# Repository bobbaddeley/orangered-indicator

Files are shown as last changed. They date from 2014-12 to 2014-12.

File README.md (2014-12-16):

orangered-indicator
===================

A tiny edge-lit display powered by a Spark Core that connects to reddit and checks for new messages. You could modify the code to check other web sites, and the edge lit display could be any icon you want. I specifically wanted to check Reddit, so I used the envelope icon.

See http://imgur.com/a/GfWCG for a full album of the completed project.

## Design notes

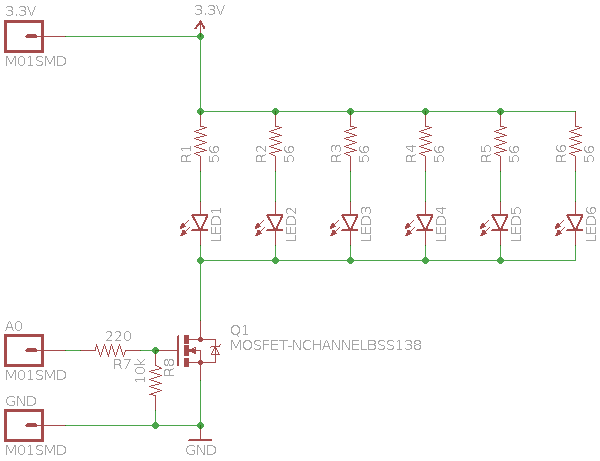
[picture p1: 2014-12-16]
schematic.png

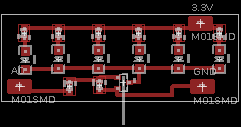
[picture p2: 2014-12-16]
board.png

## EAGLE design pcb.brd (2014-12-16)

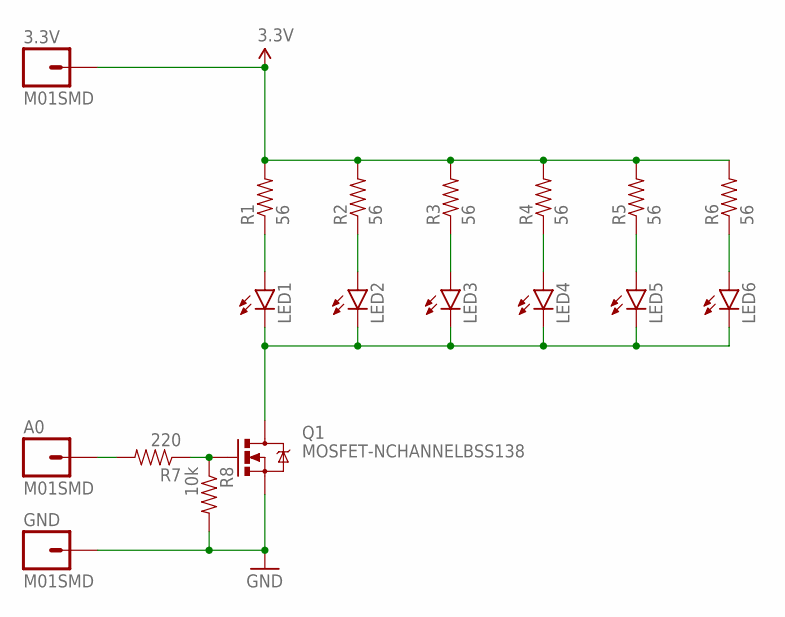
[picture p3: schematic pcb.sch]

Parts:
3.3V: M01SMD; LUXEON-PAD
A0: M01SMD; LUXEON-PAD
GND: M01SMD; LUXEON-PAD
LED1, LED2, LED3, LED4, LED5, LED6: LED1206; LED-1206
Q1: MOSFET-NCHANNELBSS138; SOT23-3
R1, R2, R3, R4, R5, R6: 56; 0603-RES
R7: 220; 0603-RES
R8: 10k; 0603-RES

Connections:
3.3V: 3.3V.P$1, R1.2, R2.2, R3.2, R4.2, R5.2, R6.2
GND: GND.P$1, Q1.2 (S), R8.2
unnamed: LED1.A, R1.1
unnamed: LED1.C, LED2.C, LED3.C, LED4.C, LED5.C, LED6.C, Q1.3 (D)
unnamed: A0.P$1, R7.2
unnamed: Q1.1 (G), R7.1, R8.1
unnamed: LED2.A, R2.1
unnamed: LED3.A, R3.1
unnamed: LED4.A, R4.1
unnamed: LED5.A, R5.1
unnamed: LED6.A, R6.1

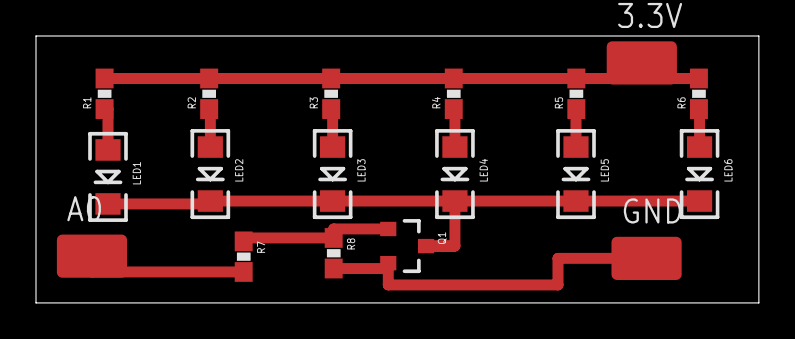
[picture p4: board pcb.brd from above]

Board: 2 copper layers, 40.2 x 14.8 mm, 18 parts (0 on the bottom side), 11 nets.

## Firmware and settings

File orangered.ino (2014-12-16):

//for the breathing of the LEDs, we do math.
#include "math.h"

//reddit username and password
char *username = "<YOURUSERNAME>";
char *password = "<YOURPASSWORD>";
//a custom user-agent because Reddit's API terms want one.
char *user_agent = "Spark Core IoT Orangered Indicator-1.0 by bobbaddeley";

//Debug mode dumps a bunch of stuff to the serial port
bool debug = false;

//how often do we check for updates
//currently every minute because we don't need to piss off Reddit
//and a minute is fine.
unsigned int frequency = 60;

TCPClient client;
unsigned int nextTime = 0;    // Next time to contact the server
//are we currently connected?
bool connected = false;
//the data that comes in from the server gets added to this string
String line = "";
//we have to send the cookie value with requests
String cookie = "";
//the output LED
int ledPin =A0; // Orange LEDs
int led2 = D7; //for debugging - built in LED
//location of the has_mail variable in the response json
int has_mail = 0;
bool mail_active = false;

void setup()
{
  //make the Spark status LED shut up.
  RGB.control(true); 
  RGB.color(0, 0, 0);
  //make the LED an output
  pinMode(ledPin, OUTPUT);
  pinMode(led2, OUTPUT);
  if (debug){
      // Make sure your Serial Terminal app is closed before powering your Core
      Serial.begin(38400);
      // Now open your Serial Terminal, and hit any key to continue!
      while(!Serial.available()) SPARK_WLAN_Loop();
      Serial.println("connecting...");
  }
  else {
    //for some reason, we can't immediately make a request, so we'll wait a bit for things to be ready
    delay(10000);
  }
  //connect to the server and log in.
  if (client.connect("reddit.com", 80))
  {
    connected = true;
    if (debug){Serial.println("connected");}
    client.print("POST /api/login?user=");
    client.print(username);
    client.print("&passwd=");
    client.print(password);
    client.println("&api_type=json&rem=true HTTP/1.1");
    client.println("Host: www.reddit.com");
    client.print("User-Agent: ");
    client.println(user_agent);
    client.println("Content-Type: text/plain;charset=UTF-8");
    client.println("Content-Length: 0");
    client.println();
  }
  else
  {
    //we didn't successfully connect to reddit. hmmm.
    connected = false;
    if (debug){Serial.println("connection failed");}
  }
    //we'll wait for 10 seconds before we make our first request for mail notification. This gives the login response some time.
    nextTime = millis() + 10000;
  
}

void loop()
{
    if (mail_active){
        //make the LED breathe. yoinked from http://sean.voisen.org/blog/2011/10/breathing-led-with-arduino/
        float val = (exp(sin(millis()/2000.0*3.14159)) - 0.36787944)*108.0;
        analogWrite(ledPin, val);
        if (debug){analogWrite(led2,val);}
    }
    else {
        analogWrite(ledPin, 0);
    }
    //if we're connected to the reddit
     if (client.available())
    {
        //and there's data to be read
        char c = client.read();
        //Serial.print(c);
        //if it's the end of a line (headers) or greater than 300 long (because the response body doesn't end in a \n
        //but for /api/me.json is longer than 300 characters)
        if (c=='\n' || line.length()>300){
            //if we've got our cookie, then we're logged in.
            if (cookie.length()>0){
                //so the line might have a has_mail string
                has_mail = line.indexOf("has_mail");
                //if it does, let's see if we have mail.
                if (has_mail>0){
                    //if we do have a has_mail string, let's see if its value is true
                    if (line.substring(has_mail+11,has_mail+15)== "true"){
                        //I have mail!!! Show the LED
                        mail_active = true;
                        digitalWrite(led2, HIGH);
                        if (debug){Serial.println("Yay! You have mail!");}
                        
                    }
                    else{
                        //No mail. :( If the LED was on before, it should be off now.
                        mail_active = false;
                        digitalWrite(led2, LOW);
                        if (debug){Serial.println("Sorry, no mail");}
                    }
                }
                //Serial.println(line);
            }
            //this line has our login cookie! Save it!
            else if (line.indexOf("set-cookie: reddit_session=")==0){
                cookie = cookie+line.substring(line.indexOf("=")+1,line.indexOf(";")+1);
            }
            //clear out the line because we're done processing it.
            line = "";
        }
        //no specialness about this character. let's add it to the string.
        else {
            line = line + c;
        }
        
    }
    //we lost our connection. weird.
    if (connected && !client.connected())
    {
        connected = false;
        if (debug){Serial.println("disconnecting.");}
    }
    //if we're not at our frequency yet, then go back to the beginning of loop.
    //this way we can loop without making the request for new mail over and over.
    if (nextTime > millis()) {
        return;
    }
    //connect to reddit and request whether we have mail or not.
    if (client.connect("reddit.com", 80))
    {
        connected = true;
        if (debug){Serial.println("connected");}
        client.println("GET /api/me.json HTTP/1.1");
        client.println("Host: www.reddit.com");
        client.print("User-Agent: ");
        client.println(user_agent);
        client.println("Content-Type: text/plain;charset=UTF-8");
        client.print("Cookie: reddit_session=");
        client.println(cookie);
        client.println("Content-Length: 0");
        client.println();
    }
    else
    {
        connected = false;
        if (debug){Serial.println("connection failed");}
    }
    //and set up the next interval to be <frequency> seconds from now.
    nextTime = millis() + (frequency*1000);
}

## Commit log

2014-12-16 The code running on the Spark Core.
    Assumes the LEDs are connected through an N Channel Mosfet to A0.
2014-12-16 Adding the board.
    [pcb.brd, pcb.sch]

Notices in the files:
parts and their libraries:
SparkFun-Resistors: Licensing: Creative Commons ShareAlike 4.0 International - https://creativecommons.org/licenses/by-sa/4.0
